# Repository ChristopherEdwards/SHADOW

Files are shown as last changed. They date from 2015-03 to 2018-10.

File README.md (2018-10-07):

Introducing S.H.A.D.O.W. (Small Handheld Arduino Droid Operating Wand) MSE Edition
A MSE droid control system based on DanF's Padawan, and Darren Blum's S.H.A.D.O.W. that uses a PS3 Move Navigation Controller

This is a fork of Darren Blum's S.H.A.D.O.W. system. It is specifically modified to support MSE (RC Car) Based Droids.

It is a slimmed down version of the original code base to only support what is used on these types of droids.
If you are already familiar with S.H.A.D.O.W. then this fork will feel very familiar.

This sketch works on an Arduino MEGA ADK, or Arduino MEGA or Arduino UNO with a USB Shield

The sketch supports the following MP3 players:

* Sparkfun MP3Trigger: https://www.sparkfun.com/products/13720
* MDFly MP3 Player: http://www.mdfly.com/products/sd-card-mp3-player-module-rs232-ttl.html
* Rouge MP3: https://roguerobotics.com/products/rmp3

Pin Assignment:
* Steering Servo: 4
* ESC: 3
* MP3 Trigger: 2

Sound Mapping:
Note: when using L2 Throttle the L2 + and L1 + keystrokes still work, though they may not be very useful
* D-pad Up - Sound 001
* D-pad Right - Sound 002
* D-pad Down - Sound 003
* D-pad Left - Random Sound 001-015
* Circle/L2 + D-pad Up - Sound 004
* Cross/L2 + D-pad Right - Sound 005
* Not Available/L2 + D-pad Down - Sound 006
* Not Available/L2 + D-pad Left - Sound 015
* L1 + D-pad Up - Volume Up
* L1 + D-pad Right - Sound 019
* L1 + D-pad Down - Volume Down
* L1 + D-pad Left - Sound 018

Additional information for the original S.H.A.D.O.W. Sketch can be found in this thread on Asromech.net:
http://astromech.net/forums/showthread.php?19298-S-H-A-D-O-W-Padawan-based-mini-PS3-Controller

All libraries distributed with original licenses as specified by the library.
serMP3 library comes from: https://forum.arduino.cc/index.php?topic=148983.0

Thank you to:
* Darren Blum aka KnightShade - S.H.A.D.O.W Sketch and rMP3 support
* MSE Droid Builders Facebook page
* Ben Black - MDFly Support
* Joe McFly - Testing support

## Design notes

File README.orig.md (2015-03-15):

Introducing S.H.A.D.O.W. (Small Handheld Arduino Droid Operating Wand)
A droid control system based on DanF's Padawan that uses a PS3 Move Navigation Controller

As I've been working with my R2, I've found that it is advantages to have a small controller that is easily concealed.

My droid initially used a PS2 controller connected to a C6C - so the controller isn't too large... and in cooler weather, I could easily conceal it within a Jacket pocket. 
During the summer however, I learned that it was much easier for those intently looking to spot the droid handler. This led me down a path toward looking at alternate controllers.

I had also wanted to have some more automation for the dome than the C6C offers.
This had me looking at PADAWAN - as aside from the C6C it used many of the same electronics that I already had in R2 - I just needed to add an Arduino into the mix.

As I started down that path - I started to look at different controller options - wondering what could interact with an Arduino.
I had heard that some were using Wii Nunchucks to control their droid - and that sounded interesting. 
As I researched wireless Wii Nunchucks - the range of the typical wireless nunchuck seemed to be limited to about 3 meters, which was too short for a droid.

In my musings, I wandered across the PS3 Move Navigation Controller:

Being essentially the left half of a PS3 controller - it was considerably smaller than what I was using. 
Its wireless was bluetooth (Class 2) which has a range of about 33 feet. 
I found a USB Host Shield from Circuits@home.com
Which had a set of drivers that would interface with wireless PS3 controllers (both the DualShock as well as the Move Navigation)

It seemed like all of the key elements existed to travel down this path - and I've been able to do so succesfully.
My droid has been successfully running this way for over 6 months now.

This project is to bring other people in on the fun, and to continue to improve the codebase.

Additional information can be found in this thread on Asromech.net:
http://astromech.net/forums/showthread.php?19298-S-H-A-D-O-W-Padawan-based-mini-PS3-Controller

-Darren Blum - aka KnightShade

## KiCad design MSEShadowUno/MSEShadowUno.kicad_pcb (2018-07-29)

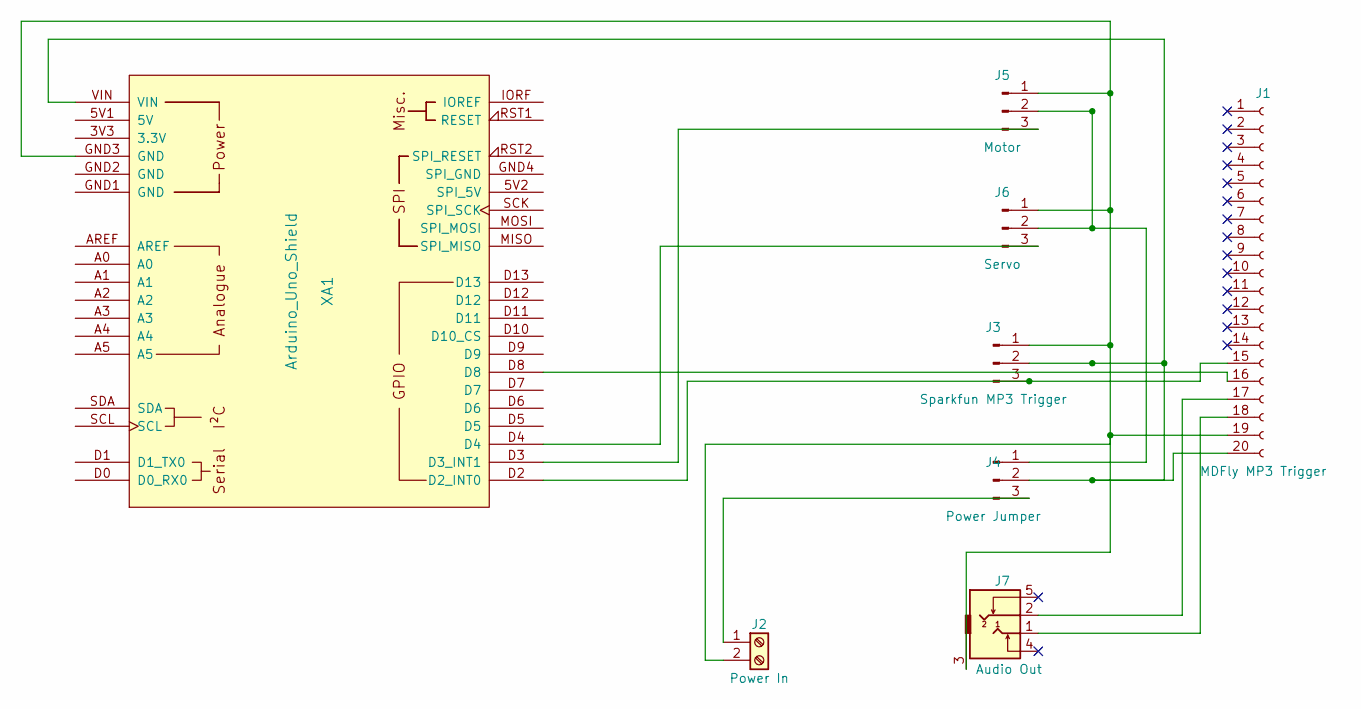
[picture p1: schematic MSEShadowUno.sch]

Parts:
J1: MDFly MP3 Trigger; Pin_Header_Straight_1x20_Pitch2.54mm
J2: Power In; TerminalBlock_Phoenix_MKDS1.5-2pol
J3: Sparkfun MP3 Trigger; Pin_Header_Straight_1x03_Pitch2.54mm
J4: Power Jumper; Pin_Header_Straight_1x03_Pitch2.54mm
J5: Motor; Pin_Header_Straight_1x03_Pitch2.54mm
J6: Servo; Pin_Header_Straight_1x03_Pitch2.54mm
J7: Audio Out; Stereo_Jack_3.5mm_Switch_Ledino_KB3SPRS
XA1: Arduino_Uno_Shield; Arduino_Uno_Shield_No_ICSP

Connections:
unnamed: J1.15, J3.3, XA1.D2 (D2_INT0)
unnamed: J1.16, XA1.D8
unnamed: J1.17, J7.2
unnamed: J1.18, J7.1
unnamed: J1.19, J2.2, J3.1, J5.1, J6.1, J7.3, XA1.GND3 (GND)
unnamed: J1.20, J3.2, J4.2, XA1.VIN
unnamed: J2.1, J4.3
unnamed: J4.1, J5.2, J6.2
unnamed: J5.3, XA1.D3 (D3_INT1)
unnamed: J6.3, XA1.D4

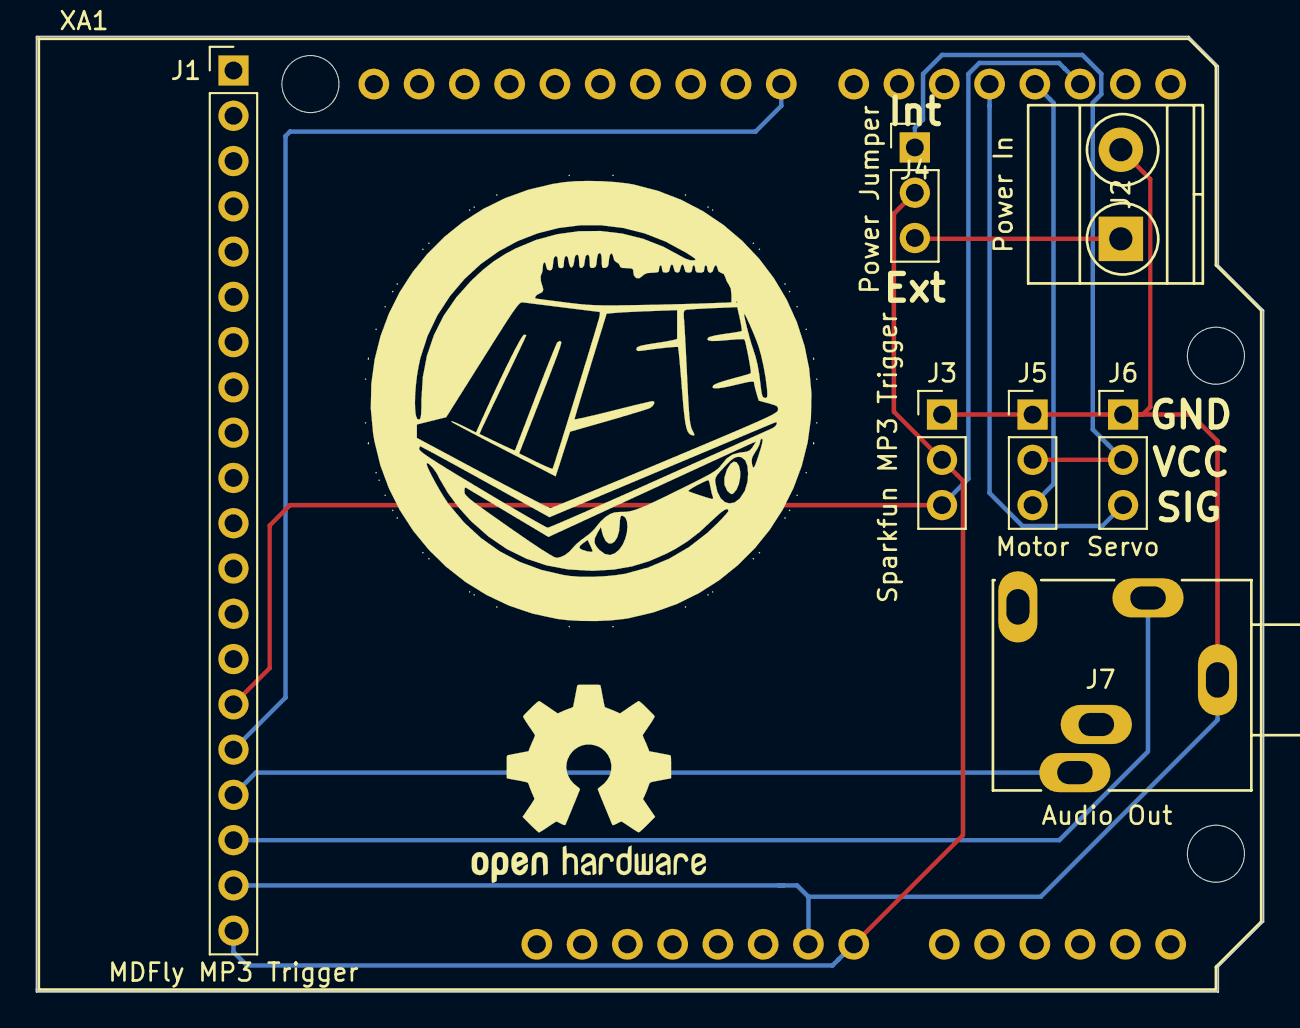
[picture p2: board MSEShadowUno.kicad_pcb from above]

Board: 2 copper layers, 68.8 x 53.6 mm, 8 parts (0 on the bottom side), 10 nets.

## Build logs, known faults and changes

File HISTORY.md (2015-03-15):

================================================================================
////////////SHADOW :  Small Handheld Arduino Droid Operating Wand///////////////
================================================================================
                          Last Revised Date: 11/14/2014
                             Written By: KnightShade
                     Heavily Influenced by PADAWAN by danf

Revision History:
-------------------------------------------------------------------------------
V5::  11/14/2014 
Alpha Release 4
Updated code for Strong
 - Merged in Fixed from Dave C. and Marty M. (MP3 Trigger)
 - Merged an altered version of Utility Arm Code and Body LED code contributed by Dave C.
 - Added support for multiple Dome communication:  Teeces Serial, Teeces I2C, AdaFruit I2C
 - With AdaFruit I2C:  Control 3 Holoprojectors with Servos and RGB LED (paired with R Series Logics)
 - Misc Fixes (InvertTurn, Fixes for Dome Automation and deadband)
 - Testing with Parani UD-100 Bluetooth w/ external Antenna
 - Extended commands sent to CFSound III (& prep for other sound systems:  rMP3 & Rasberry Pi)

-------------------------------------------------------------------------------
V4::  09/13/2014 
Alpha Release 3
Updated code for Scare-a-con
 - Updated dome sketch to resolve communication issues, and "stalled" transition pattern
 - Ported dome serial to Hardware Serial.  This resolved Dome Communication
 - Tweaked some sound controls (L1 vs PS)

-------------------------------------------------------------------------------
V3::  09/01/2014 
Alpha Release 2
Updated code for FanExpo in Toronto, code base is approaching "stable"
 - Reworked the flow of "ps3FootMotorDrive" - successfully resolved issue #1 from v2
 - Resolve Latency Issues by converting to HardwareSerial resolving issue #2 from v2
 - Added a 10ms gap between SyRen.motor calls
		This was an alternate solution to #2, and ensures serial time for foot motors
 - Chained the Syren and Sabertooth - while removing legacy SimplifiedSyren support.  
 - Reduced the timeouts for the SyRen and Sabertooth to 300ms (quicker shutoff in absense of Commands)
 - Added "Quick Disconnect" for Controller (PS+L3)
 - Updated Holo movement, moving it to L1-"D-pad" due to changes in Joystick control

Other updates pending:
	Further refinement of Controller #2
-------------------------------------------------------------------------------
V2::  08/24/2014
Alpha Release 1
Initial test release, used at the Baldwinsville Min-Con Library event
 - Base functionality all there.
 - Added support for a second PS3 Move Navigation Controller
 - Initial support for SPP (Bluetooth Serial Monitor)
 - Latency for the foot motors has been traced down to a conflict 
		with the dome code flooding the serial channels.
 - Code added to reduce serial chatter after the motors are stopped.

Major Bugs found in this release:
1.)Spinning the dome with the joystick is causing the foot motors to go.
	Placed the SyRen&Sabertooth onto different addresses - this did NOT resolve the issue
2.)	I now suspect that the flooding issue may have been related to SoftwareSerial buffer size.  
		As the MEGA has 3 hardware uarts - move the motors to use Hardware, (possibly chained).
-------------------------------------------------------------------------------
V1::  08/10/2014  
Pre-Alpha Release
Prototype code, to evaluate feasibility
 - Support for Single Move Navigation Controller
 - Code was all inline - minimal deviation from Padawan base code

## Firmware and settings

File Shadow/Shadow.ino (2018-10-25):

// =======================================================================================
//                 SHADOW :  Small Handheld Arduino Droid Operating Wand
// =======================================================================================
//                          Last Revised Date: 10/05/14
//                             Written By: KnightShade
//                        Inspired by the PADAWAN by danf
//                              Hacked By: CJE1985
// =======================================================================================
//
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
// =======================================================================================
//   Note: You will need a Arduino Mega 2560 or Uno to run this sketch
//
//   This is written to be a UNIVERSAL Sketch - supporting multiple controller options
//      - Single PS3 Move Navigation
//      - Pair of PS3 Move Navigation
//
//   PS3 Bluetooth library - developed by Kristian Lauszus (kristianl@tkjelectronics.com)
//   For more information visit my blog: http://blog.tkjelectronics.dk/ or
//
// =======================================================================================
//        Updated:  12/26/2017
// ---------------------------------------------------------------------------------------
//                          User Settings
// ---------------------------------------------------------------------------------------

//Primary Controller
String PS3MoveNavigatonPrimaryMAC = "04:76:6E:5A:9A:5B"; //If using multiple controlers, designate a primary

byte joystickDeadZoneRange = 10;  // For controllers that centering problems, use the lowest number with no drift

int steeringNeutral = 90;        // Move this by one or two to set the center point for the steering servo

#define reverseSteering          // Comment this to have normal stering direction (Lots of RC cars are built with reverseSteering by default)
int steeringRightEndpoint = 120; // Move this down (below 180) if you need to set a narrower Right turning radius
int steeringLeftEndpoint = 0;    // Move this up (above 0) if you need to set a narrower Left turning radius

int driveNeutral = 91;           // Move this by one or two to set the center point for the drive ESC
int maxForwardSpeed = 115;       // Move this down (below 180, but above 90) if you need a slower forward speed
int maxReverseSpeed = 65;        // Move this up (above 0, but below 90) if you need a slower reverse speed

//#define TEST_CONROLLER         //Support coming soon
//#define SHADOW_DEBUG           //uncomment this for console DEBUG output
#define SHADOW_VERBOSE           //uncomment this for console VERBOSE output

// ---------------------------------------------------------------------------------------
//                          Drive Controller Settings
// ---------------------------------------------------------------------------------------

#define steeringPin 4            // connect this pin to steering servo for MSE (R/C mode)
#define drivePin 3               // connect this pin to ESC for forward/reverse drive (R/C mode)
#define L2Throttle               // comment this to use Joystick throttle (instead of L2 throttle)

// ---------------------------------------------------------------------------------------
//                          Sound Control Settings
// ---------------------------------------------------------------------------------------

#define MP3TxPin 2               // connect this pin to the MP3 Trigger
#define MP3RxPin 8               // This pin isn't used by the sparkfun MP3 trigger, but is used by the MDFly
//#define Sparkfun               // Use the sparkfun MP3 Trigger
#define MDFly                    // Use the MDFly MP3 Player
//#define RogueRMP3              // Use the Rogue RMP3 Player


// ---------------------------------------------------------------------------------------
//                          Libraries
// ---------------------------------------------------------------------------------------
#include <PS3BT.h>
#include <Servo.h>


#ifdef RogueRMP3
#include <RogueMP3.h>
#include <SoftwareSerial.h>
SoftwareSerial rmp3_s = SoftwareSerial(MP3TxPin, MP3RxPin);
RogueMP3 MP3(rmp3_s);
#endif


#ifdef Sparkfun
#include <MP3Trigger.h>
#include <SoftwareSerial.h>
SoftwareSerial swSerial = SoftwareSerial(MP3RxPin, MP3TxPin);
MP3Trigger MP3;
#endif

#ifdef MDFly
#include <serMP3.h>
serMP3 MP3(MP3TxPin, MP3RxPin);
#endif

// ---------------------------------------------------------------------------------------
//                          Variables
// ---------------------------------------------------------------------------------------

long previousMillis = millis();
long currentMillis = millis();
int serialLatency = 25;          // This is a delay factor in ms to prevent queueing of the Serial data.
                                 // 25ms seems approprate for HardwareSerial, values of 50ms or larger
                                 // are needed for Softare Emulation

///////Setup for USB and Bluetooth Devices////////////////////////////
USB Usb;
BTD Btd(&Usb);                   // You have to create the Bluetooth Dongle instance like so
PS3BT *PS3Nav = new PS3BT(&Btd);
PS3BT *PS3Nav2 = new PS3BT(&Btd);
//Used for PS3 Fault Detection
uint32_t msgLagTime = 0;
uint32_t lastMsgTime = 0;
uint32_t currentTime = 0;
uint32_t lastLoopTime = 0;
int badPS3Data = 0;

boolean firstMessage = true;
String output = "";

boolean isDriveMotorStopped = true;

boolean isPS3NavigatonInitialized = false;
boolean isSecondaryPS3NavigatonInitialized = false;

byte vol = 0;                   // 0 = full volume, 255 off for MP3Trigger, the MDFly use a 0-31 vol range
boolean isStickEnabled = true;

byte action = 0;
unsigned long DriveMillis = 0;

Servo steeringSignal;
Servo driveSignal;
int steeringValue, driveValue;   //will hold steering/drive values (-100 to 100)
int prevSteeringValue, prevDriveValue; //will hold steering/drive speed values (-100 to 100)


// =======================================================================================
//                          Main Program
// =======================================================================================

void setup()
{
  //Debug Serial for use with USB Debugging
  Serial.begin(115200);
  while (!Serial); // Wait for serial port to connect - used on Leonardo, Teensy and other boards with built-in USB CDC serial connection
  if (Usb.Init() == -1)
  {
    Serial.print(F("\r\nOSC did not start"));
    while (1); //halt
  }
  Serial.print(F("\r\nBluetooth Library Started"));
  output.reserve(200); // Reserve 200 bytes for the output string

  //Setup for PS3
  PS3Nav->attachOnInit(onInitPS3); // onInit() is called upon a new connection - you can call the function whatever you like
  PS3Nav2->attachOnInit(onInitPS3Nav2);


#ifdef RogueRMP3
  rmp3_s.begin(9600);
  MP3.sync();
  MP3.stop();
  MP3.setVolume(vol);
  Serial.print(F("\r\nRogue rMP3 Initialized"));
#endif


#ifdef Sparkfun
  //Setup for SoftwareSerial/MP3 Trigger
  MP3.setup(&swSerial);
  swSerial.begin(MP3Trigger::serialRate());
  MP3.setVolume(vol);
  Serial.print(F("\r\nSparkfun MP3 Trigger Initialized"));
#endif

#ifdef MDFly
  MP3.begin(vol);
  Serial.print(F("\r\nMDFly MP3 Initialized"));
#endif

  Serial.print(F("\r\nMSE Drive Running"));
  steeringSignal.attach(steeringPin);
  driveSignal.attach(drivePin);
}

boolean readUSB()
{
  //The more devices we have connected to the USB or BlueTooth, the more often Usb.Task need to be called to eliminate latency.
  Usb.Task();
  if (PS3Nav->PS3NavigationConnected ) Usb.Task();
  if (PS3Nav2->PS3NavigationConnected ) Usb.Task();
  if ( criticalFaultDetect() )
  {
    //We have a fault condition that we want to ensure that we do NOT process any controller data!!!
    flushAndroidTerminal();
    return false;
  }
  return true;
}

void loop()
{
  //Useful to enable with serial console when having controller issues.
#ifdef TEST_CONROLLER
  testPS3Controller();
#endif

  //LOOP through functions from highest to lowest priority.

  if ( !readUSB() )
  {
    //We have a fault condition that we want to ensure that we do NOT process any controller data!!!
    return;
  }
  Drive();

  if ( !readUSB() )
  {
    //We have a fault condition that we want to ensure that we do NOT process any controller data!!!
    return;
  }

  toggleSettings();
  soundControl();
  flushAndroidTerminal();
}

void onInitPS3()
{
  String btAddress = getLastConnectedBtMAC();
  PS3Nav->setLedOn(LED1);
  isPS3NavigatonInitialized = true;
  badPS3Data = 0;
#ifdef SHADOW_DEBUG
  output += "\r\nBT Address of Last connected Device when Primary PS3 Connected: ";
  output += btAddress;
  if (btAddress == PS3MoveNavigatonPrimaryMAC)
  {
    output += "\r\nWe have our primary controller connected.\r\n";
  }
  else
  {
    output += "\r\nWe have a controller connected, but it is not designated as \"primary\".\r\n";
  }
#endif
}

void onInitPS3Nav2()
{
  String btAddress = getLastConnectedBtMAC();
  PS3Nav2->setLedOn(LED1);
  isSecondaryPS3NavigatonInitialized = true;
  badPS3Data = 0;
  if (btAddress == PS3MoveNavigatonPrimaryMAC) swapPS3NavControllers();
#ifdef SHADOW_DEBUG
  output += "\r\nBT Address of Last connected Device when Secondary PS3 Connected: ";
  output += btAddress;
  if (btAddress == PS3MoveNavigatonPrimaryMAC)
  {
    output += "\r\nWe have our primary controller connecting out of order.  Swapping locations\r\n";
  }
  else
  {
    output += "\r\nWe have a secondary controller connected.\r\n";
  }
#endif
}

String getLastConnectedBtMAC()
{
  String btAddress = "";
  for (int8_t i = 5; i > 0; i--)
  {
    if (Btd.disc_bdaddr[i] < 0x10)
    {
      btAddress += "0";
    }
    btAddress += String(Btd.disc_bdaddr[i], HEX);
    btAddress += (":");
  }
  btAddress += String(Btd.disc_bdaddr[0], HEX);
  btAddress.toUpperCase();
  return btAddress;
}

void swapPS3NavControllers()
{
  PS3BT* temp = PS3Nav;
  PS3Nav = PS3Nav2;
  PS3Nav2 = temp;
  //Correct the status for Initialization
  boolean tempStatus = isPS3NavigatonInitialized;
  isPS3NavigatonInitialized = isSecondaryPS3NavigatonInitialized;
  isSecondaryPS3NavigatonInitialized = tempStatus;
  //Must relink the correct onInit calls
  PS3Nav->attachOnInit(onInitPS3);
  PS3Nav2->attachOnInit(onInitPS3Nav2);
}

void flushAndroidTerminal()
{
  if (output != "")
  {
    if (Serial) Serial.println(output);
    output = ""; // Reset output string
  }
}

// =======================================================================================
// //////////////////////////Process PS3 Controller Fault Detection///////////////////////
// =======================================================================================
boolean criticalFaultDetect()
{
  if (PS3Nav->PS3NavigationConnected || PS3Nav->PS3Connected)
  {
    lastMsgTime = PS3Nav->getLastMessageTime();
    currentTime = millis();
    if ( currentTime >= lastMsgTime)
    {
      msgLagTime = currentTime - lastMsgTime;
    } else
    {
#ifdef SHADOW_DEBUG
      output += "Waiting for PS3Nav Controller Data\r\n";
#endif
      badPS3Data++;
      msgLagTime = 0;
    }

    if (msgLagTime > 100 && !isDriveMotorStopped)
    {
#ifdef SHADOW_DEBUG
      output += "It has been 100ms since we heard from the PS3 Controller\r\n";
      output += "Shut downing motors, and watching for a new PS3 message\r\n";
#endif

      driveSignal.write(driveNeutral);
      steeringSignal.write(steeringNeutral);
      isDriveMotorStopped = true;
      return true;
    }
    if ( msgLagTime > 30000 )
    {
#ifdef SHADOW_DEBUG
      output += "It has been 30s since we heard from the PS3 Controller\r\n";
      output += "msgLagTime:";
      output += msgLagTime;
      output += "  lastMsgTime:";
      output += lastMsgTime;
      output += "  millis:";
      output += millis();
      output += "\r\nDisconnecting the controller.\r\n";
#endif
      PS3Nav->disconnect();
    }

    //Check PS3 Signal Data
    if (!PS3Nav->getStatus(Plugged) && !PS3Nav->getStatus(Unplugged))
    {
      // We don't have good data from the controller.
      //Wait 10ms, Update USB, and try again
      delay(10);
      Usb.Task();
      if (!PS3Nav->getStatus(Plugged) && !PS3Nav->getStatus(Unplugged))
      {
        badPS3Data++;
#ifdef SHADOW_DEBUG
        output += "\r\nInvalid data from PS3 Controller.";
#endif
        return true;
      }
    }
    else if (badPS3Data > 0)
    {
      //output += "\r\nPS3 Controller  - Recovered from noisy connection after: ";
      //output += badPS3Data;
      badPS3Data = 0;
    }
    if ( badPS3Data > 10 )
    {
#ifdef SHADOW_DEBUG
      output += "Too much bad data coming fromo the PS3 Controller\r\n";
      output += "Disconnecting the controller.\r\n";
#endif
      PS3Nav->disconnect();
    }
  }
  else if (!isDriveMotorStopped)
  {
#ifdef SHADOW_DEBUG
    output += "No Connected Controllers were found\r\n";
    output += "Shuting downing motors, and watching for a new PS3 message\r\n";
#endif

    driveSignal.write(driveNeutral);
    steeringSignal.write(steeringNeutral);
    isDriveMotorStopped = true;
    return true;
  }
  return false;
}
// =======================================================================================
// //////////////////////////END of PS3 Controller Fault Detection///////////////////////
// =======================================================================================


boolean ps3Drive(PS3BT* myPS3 = PS3Nav)
{
  if (isPS3NavigatonInitialized) {
    // Additional fault control.  Do NOT send additional commands if no controllers have initialized.
    if (!isStickEnabled) {
      #ifdef SHADOW_VERBOSE
      if ( abs(myPS3->getAnalogHat(LeftHatY) - 128) > joystickDeadZoneRange)
      {
        output += "Drive Stick is disabled\r\n";
      }
      #endif

      driveSignal.write(driveNeutral);
      steeringSignal.write(steeringNeutral);
      isDriveMotorStopped = true;
      
    } else if (!myPS3->PS3NavigationConnected) {
      driveSignal.write(driveNeutral);
      steeringSignal.write(steeringNeutral);
      isDriveMotorStopped = true;

    } else {
      int stickX = myPS3->getAnalogHat(LeftHatX);
      #ifdef L2Throttle
      int stickY = myPS3->getAnalogButton(L2);
      #else
      int stickY = myPS3->getAnalogHat(LeftHatY);
      #endif

      #ifdef L2Throttle
      // map the steering direction
      if (((stickX <= 128 - joystickDeadZoneRange) || (stickX >= 128 + joystickDeadZoneRange))) {
        #ifdef reverseSteering
          steeringValue = map(stickX, 0, 255, steeringRightEndpoint, steeringLeftEndpoint);
        #else
          steeringValue = map(stickX, 0, 255, steeringLeftEndpoint, steeringRightEndpoint);
        #endif
      } else {
        steeringValue = steeringNeutral;
        driveValue = driveNeutral;
      }

      // map the drive direction
      if (myPS3->getButtonPress(L1) && myPS3->getAnalogButton(L2)) {
        // These values must cross 90 (as that is stopped)
        // The closer these values are the more speed control you get
        driveValue = map(stickY, 0, 255, 90, maxReverseSpeed);
      } else if (myPS3->getAnalogButton(L2)) {
        // These values must cross 90 (as that is stopped)
        // The closer these values are the more speed control you get
        driveValue = map(stickY, 0, 255, 90, maxForwardSpeed);
      }
      #else
      if (((stickX <= 128 - joystickDeadZoneRange) || (stickX >= 128 + joystickDeadZoneRange)) ||
          ((stickY <= 128 - joystickDeadZoneRange) || (stickY >= 128 + joystickDeadZoneRange))) {
            #ifdef reverseSteering
              steeringValue = map(stickX, 0, 255, steeringRightEndpoint, steeringLeftEndpoint);
            #else
              steeringValue = map(stickX, 0, 255, steeringLeftEndpoint, steeringRightEndpoint);
            #endif
            // These values must cross 90 (as that is stopped)
            // The closer these values are the more speed control you get
            driveValue = map(stickY, 0, 255, maxForwardSpeed, maxReverseSpeed);
      } else {
        // stop all movement
        steeringValue = steeringNeutral;
        driveValue = driveNeutral;
      }
      #endif

      driveSignal.write(driveValue);
      steeringSignal.write(steeringValue);

      return true; //we sent a drive command
    }
  }
  return false;
}


void ps3ToggleSettings(PS3BT* myPS3 = PS3Nav)
{
  if (myPS3->getButtonPress(PS) && myPS3->getButtonClick(L3))
  {
    //Quick Shutdown of PS3 Controller
    output += "\r\nDisconnecting the controller.\r\n";
    myPS3->disconnect();
  }


  //// enable / disable right stick & play sound
  if (myPS3->getButtonPress(PS) && myPS3->getButtonClick(CROSS))
  {
#ifdef SHADOW_DEBUG
    output += "Disiabling the DriveStick\r\n";
#endif
    isStickEnabled = false;
    //        MP3.play(52);
  }
  if (myPS3->getButtonPress(PS) && myPS3->getButtonClick(CIRCLE))
  {
#ifdef SHADOW_DEBUG
    output += "Enabling the DriveStick\r\n";
#endif
    isStickEnabled = true;
    ///        MP3.play(53);
  }
}

void processSoundCommand(char soundCommand)
{
  switch (soundCommand)
  {
    case '-':
#ifdef SHADOW_DEBUG
      output += "Volume Down\r\n";
#endif
      if (vol > 0)
      {

#ifdef RogueRMP3
        vol = vol-10;
        if (vol < 0 ) { vol = 0; }
        MP3.setVolume(vol);
#endif

#ifdef MDFly
        vol--;
        MP3.setVol(vol);
#endif

#ifdef Sparkfun
        vol = vol-5;
        if (vol < 0 ) { vol = 0 ;}
        MP3.setVolume(vol);
#endif

      }
      break;
    case '+':
#ifdef SHADOW_DEBUG
      output += "Volume Up\r\n";
#endif

#ifdef RogueRMP3
        if (vol < 255) {
          vol = vol+10;
          if (vol > 255 ) { vol = 255 ;}
          MP3.setVolume(vol);
        }
#endif

#ifdef MDFly
      // The TDB380 and 381 use a 0-31 vol range
      if (vol < 31) {
          vol++;
          MP3.setVol(vol);
      }
#endif

#ifdef Sparkfun
        // The MP3Trigger use a 0-255 vol range
        if (vol < 255) {
          vol = vol+5;
          if (vol > 255 ) { vol = 255 };
          MP3.setVolume(vol);
        }
#endif

        break;

      case '1':
#ifdef SHADOW_DEBUG
        output += "Sound Button ";
        output += soundCommand;
        output += " - Play Scream\r\n";
#endif

#ifdef MDFly
        MP3.play(1);
#endif

#ifdef Sparkfun
        MP3.trigger(1);
#endif

#ifdef RogueRMP3
        MP3.playFile("/MSE01.mp3");
#endif


        break;
      case '2':
#ifdef SHADOW_DEBUG
        output += "Sound Button ";
        output += soundCommand;
        output += " - Play Doo Doo.\r\n";
#endif

#ifdef RogueRMP3
        MP3.playFile("/MSE02.mp3");
#endif

#ifdef MDFly
        MP3.play(2);
#endif

#ifdef Sparkfun
        MP3.trigger(2);
#endif

        break;
      case '3':
#ifdef SHADOW_DEBUG
        output += "Sound Button ";
        output += soundCommand;
        output += " - Play Scramble\r\n";
#endif

#ifdef RogueRMP3
        MP3.playFile("/MSE03.mp3");
#endif

#ifdef MDFly
        MP3.play(3);
#endif

#ifdef Sparkfun
        MP3.trigger(3);
#endif

        break;
        case '4':
#ifdef SHADOW_DEBUG
        output += "Sound Button ";
        output += soundCommand;
        output += " - Play Scramble\r\n";
#endif

#ifdef RogueRMP3
        MP3.playFile("/Mouse Droid Song.mp3");
#endif

#ifdef MDFly
        MP3.play(4);
#endif

#ifdef Sparkfun
        MP3.trigger(4);
#endif

        break;
      case '5':
#ifdef SHADOW_DEBUG
        output += "Sound Button ";
        output += soundCommand;
        output += " - Play Mouse Sound.\r\n";
#endif

#ifdef RogueRMP3
        MP3.playFile("/MSE04.mp3");
#endif

#ifdef MDFly
        MP3.play(5);
#endif

#ifdef Sparkfun
        MP3.trigger(5);
#endif

        break;
      case '6':
#ifdef SHADOW_DEBUG
        output += "Sound Button ";
        output += soundCommand;
        output += " - Play Crank Sound.\r\n";
#endif

#ifdef RogueRMP3
        MP3.playFile("/MSE05.mp3");
#endif

#ifdef MDFly
        MP3.play(6);
#endif

#ifdef Sparkfun
        MP3.trigger(6);
#endif

        break;
      case '7':
#ifdef SHADOW_DEBUG
        output += "Sound Button ";
        output += soundCommand;
        output += " - Play Splat.\r\n";
#endif

#ifdef RogueRMP3
        MP3.playFile("/MSE06.mp3");
#endif

#ifdef MDFly
        MP3.play(7);
#endif

#ifdef Sparkfun
        MP3.trigger(7);
#endif

        break;
      case '8':
#ifdef SHADOW_DEBUG
        output += "Sound Button ";
        output += soundCommand;
        output += " - Play Electrical.\r\n";
#endif

#ifdef RogueRMP3
        MP3.playFile("/March.mp3");
#endif

#ifdef MDFly
        MP3.play(8);
#endif

#ifdef Sparkfun
        MP3.trigger(15);
#endif

        break;
      case '9':
#ifdef SHADOW_DEBUG
        output += "Sound Button ";
        output += soundCommand;
        output += " - Play March L1+L.\r\n";
#endif

#ifdef RogueRMP3
        MP3.playFile("/MSE10.mp3");
#endif

#ifdef MDFly
        MP3.play(9);
#endif

#ifdef Sparkfun
        MP3.trigger(18);
#endif

        break;
      case '0':
#ifdef SHADOW_DEBUG
        output += "Sound Button ";
        output += soundCommand;
        output += " - Play Cantina L1+R\r\n";
#endif

#ifdef RogueRMP3
        MP3.playFile("/MSE11.mp3");
#endif

#ifdef MDFly
        MP3.play(10);
#endif

#ifdef Sparkfun
        MP3.trigger(19);
#endif

        break;
      case 'A':
#ifdef SHADOW_DEBUG
        output += "Sound Button ";
        output += soundCommand;
        output += " - Play Jabba Flow L1+O\r\n";
#endif

#ifdef RogueRMP3
        MP3.playFile("/Cantina.mp3");
#endif

#ifdef MDFly
        MP3.play(11);
#endif

#ifdef Sparkfun
        MP3.trigger(20);
#endif

        break;
      case 'B':
#ifdef SHADOW_DEBUG
        output += "Sound Button ";
        output += soundCommand;
        output += " - Play SWG Music L1+X\r\n";
#endif

#ifdef RogueRMP3
        MP3.playFile("/March.mp3");
#endif

#ifdef MDFly
        MP3.play(12);
#endif
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

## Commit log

2017-11-21 Move sketch to folder with the same name
    The arduino IDE requires that the sketch be in a folder with the
    same name with nothing else in it.
2017-11-21 Implement L2 throttle and slim code base even more
    Use L2 for throttle to allow for better steering
    Remove code not used for MSE Droids
    Slim code base to support Arduino UNO
2017-11-21 Add Arduino UNO sized shield design
    [SHADOW MSE Edition UNO Shield.fzz]
2017-11-21 Update Readme for slimmed down sketch
    Arduino pins moved around and additional sound buttons are mapped
2017-11-23 Change pin assignments to work with USB host shields
    Completed testing on Arduino UNO and USB Host Shield, which now works
    Beware of the ICSP pin duplication on the Digital pins 9-13, these
    are effictively unusable pins now.
2017-11-23 Add MDFly MP3 player support
    Thanks to Ben Black for the MDFly MP3 Player support.
    * Integrated provided code to support either the Sparkfun MP3Trigger or
    the MDFly MP3 Player
    * Updated README with board URLs
    * Fixed formatting of sketch
    * Make sure the MP3 Player Pin is configurable
    * Add serMP3 library
    [Shadow.ino]
2017-11-23 Fix steering bug
    The previous code would only allow steering if throttle input was given
    [Shadow.ino]
2018-04-26 Update PCB Board Shield
    [SHADOW MSE Edition UNO Shield.fzz]
2018-05-17 Add KiCad board layout
    [MSEShadowUno-B.Cu.gbl, MSEShadowUno-B.Mask.gbs, MSEShadowUno-B.SilkS.gbo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]
2018-07-29 Update PCB Board
    Update PCB board to use Arduino Uno Shield instead of Atmel chip
    (this fixes routing problems between the schematic and PCB)
    Remove generated Gerber files
    [MSEShadowUno-B.Cu.gbl, MSEShadowUno-B.Mask.gbs, MSEShadowUno-B.SilkS.gbo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]
2018-07-29 Add gitignore for gerber files and backups
    Gerber files are generated from KiCad and shouldn't be version controlled
    Backup files are unnecessary to be version controlled
2018-08-12 Fix issues with Joystick throttle, add reverse steering option
    * Joystick throttle didn't work due to refering to a changed variable
    name for the joystick deadzone. Change to proper variable name
    * Add reverse steering option so left and right always refer to the
    correct direction, but the output from the arduino is reveresed
    * Cleaned up comment formatting
    [Shadow.ino]
2018-10-06 Fix reverse steering option
    Inadvertently didn't apply the reverse steering option to L2 Throttle
    [Shadow.ino]
2018-10-07 Volume control case logic had +/- swapped
    [Shadow.ino]
2018-10-21 Integrate Ryan Diaz's changes to prevent duplicate sounds
    Ryan Diaz provided changes to prevent duplicate sounds and a sound
    to key map (PS3NavButtonMap.txt)
    [Shadow.ino]
